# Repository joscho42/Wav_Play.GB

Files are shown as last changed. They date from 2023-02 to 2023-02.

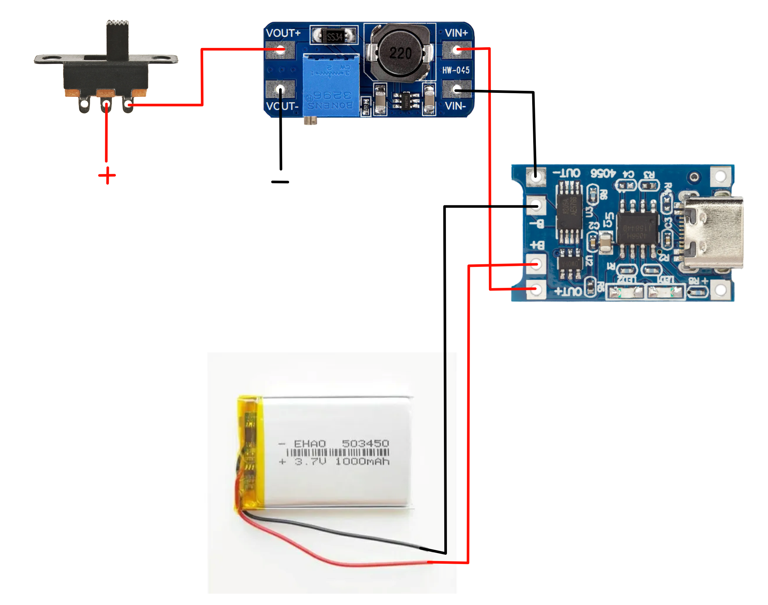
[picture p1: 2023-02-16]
Documentation/Power_managment.png

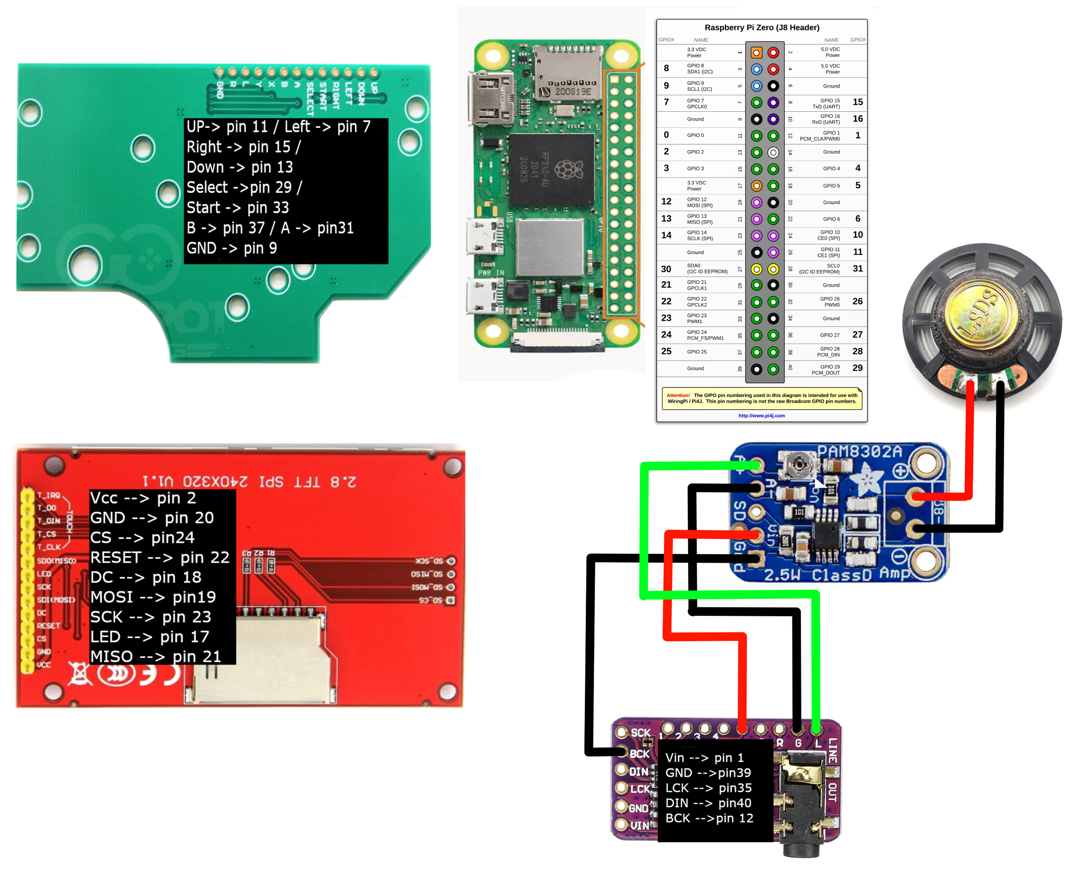
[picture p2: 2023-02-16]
Documentation/Audio_Input_Video.png

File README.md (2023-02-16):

# Wav_Play.GB

Check out the Manual in the Documentation
folder of the rep (German and English)



## About the project

This is a rep for the Wav_Play.GB.

The Wav_Play.GB is a handheld Stepsequencer with up to 192 Steps and up too 6 voices.
It allows you to creat your own sample library and creat tracks on the go all in a familiar form factor.
At it´s heart is a Raspberry pi Zero 2W

It was born out of a University project.
Find out more on Instagram @wav_play.gb

##Turning the device on and off

To turn the Wav_Play.GB on, simply swich the power switch to the right.
To turn it off ** dont´t just switch the power switch to the left **
Go into the menue ofthe pyquencer, navigate to Shut Down and press A.
Wait until the led on the raspberry is of (the screen will still be on and white).
Than Switch the power switch to the left.

## Setting up the SD card and USB

Fist you will want to set up the SD card. For that you simply need to flash our custom img file using 
the Raspberry Pi Imager.
Found here: https://drive.google.com/drive/folders/1ieQOY9xSynMFqbqVy8Zn_2mXZG3F-kP7?usp=share_link

To set up the USB first format it to Fat32 and rename it to PYQUENCER (all caps).
Than Download the Usb_Root folder here:
https://drive.google.com/drive/folders/1ieQOY9xSynMFqbqVy8Zn_2mXZG3F-kP7?usp=share_link
and add the files to the root of your usb.

Congrats. You are all set. Plug the SD card and USB in your Wav_Play.GB and go wild

## Buildguide

A video build guide can be found here: https://youtu.be/5e7-cO_Iyow

#### Installing the Battery

Battery installation is highly dependent of the size of your battery. 
We recoment using a battery with the dimensions: 54x34x10mm
Those dismensions work perfectly with JRodrigos battery holder design 
over on Thingivers (https://www.thingiverse.com/thing:1418834)Power_managment

Simply guide the two leads of your battery through the little hole on the left of the holder 
and torugh the hole in the gameboy case. 
Put the holder and the battery in the compartment using the springs to hold it in place.
Close the compartment and you are done.

#### Wirering of the power side

Power_managment

#### Wiring of the Audio, Video, and input side: 

Audio_Input_Video

***Don´t forget to bridge the two pads under the SCK printing on the Headphone Jack board***

#### Combinig both halves:

When everything is wired up, simply connect the micro usb to usb adapter to the Raspberry and solder in the positif and negative leads to the back of the Raspberry marked 5V and the unmarked pin underneath close to the Power in micro usb port.

## Troubleshooting

If your wav_play.gb doesn´t find your USB you can do a USB Recovery by plugin the USB into your computer and renaming it USB_REC than pluging it backl in your Wav_Play.GB

The device will fix the problem and shut down on it´s own.

Put the USB back into your PC and name it back to PYQUENCER and everything should be fine again.

Video explenation: https://youtu.be/XgMAqk8Z5bY

## Adding your own library

This Video explains how to add your own library
https://www.youtube.com/watch?v=3tRRe0SVF7o

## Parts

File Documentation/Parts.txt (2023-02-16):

-Gameboy Housing
-Rasperry pi Zero W2
-micro sd Karte
-PCM5102 I2S Digital Audio DAC
-Small usb stick minimum 8GB
-3.7v 1800mAh Lipo
-TP4056 Lithium battery charging module
-MT3608 Voltage Booster
-2.8" SPI TFT LCD 
-Micro usb to usb adapter
-PAM8302 Adafruit Mono 2.5W Class D Audio Amplifier
-Gameboy Speaker 
-Gameboy Button PCB 
-ON/OFF switch 
-Cabels
-3D printed parts

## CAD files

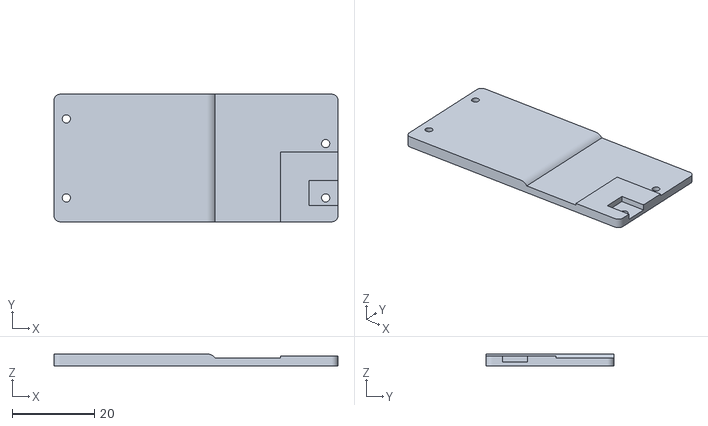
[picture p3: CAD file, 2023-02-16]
3D files/Backplate.stl
69.0 x 31.0 x 3.00

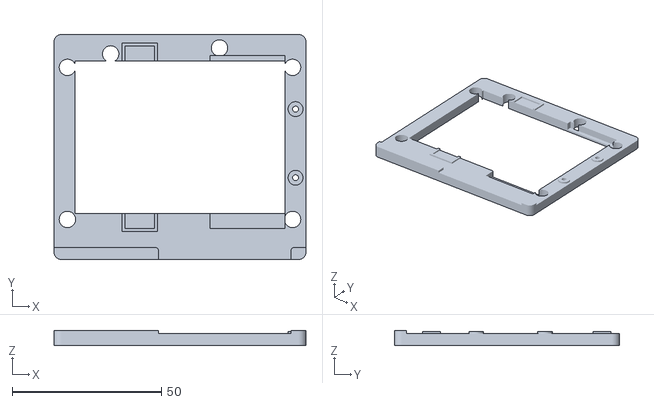
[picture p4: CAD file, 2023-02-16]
3D files/Screen_Holder.stl
84.5 x 75.5 x 5.00

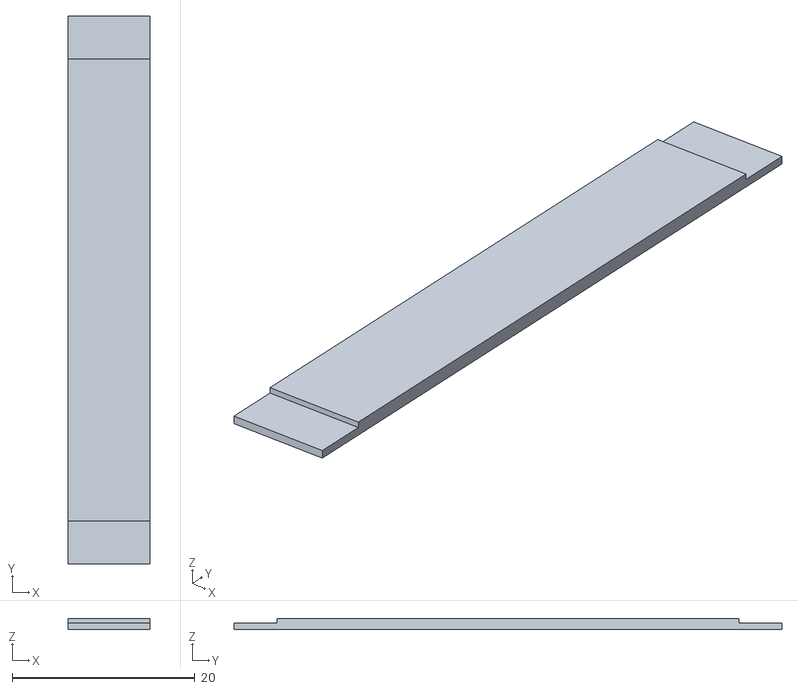
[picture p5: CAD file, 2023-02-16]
3D files/Sceen_Holder_2.stl
9.00 x 60.0 x 1.20

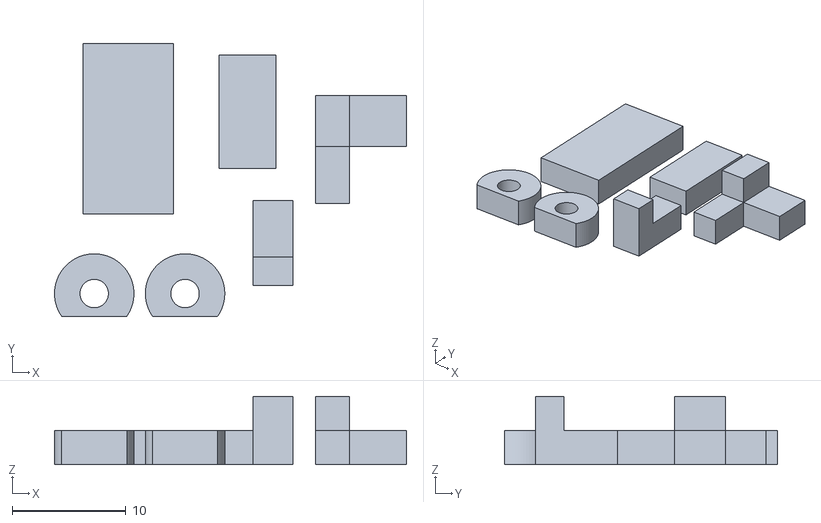
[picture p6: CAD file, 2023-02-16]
3D files/Small_Parts.stl
31.0 x 24.0 x 6.00

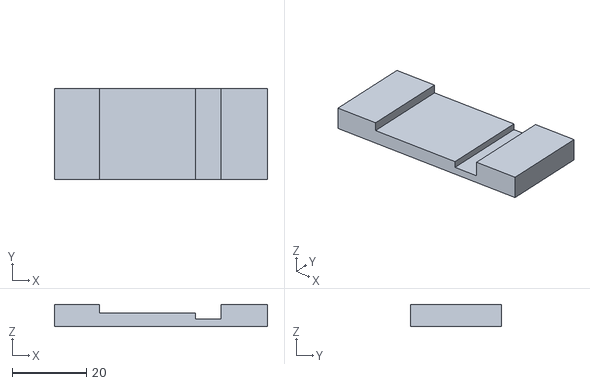
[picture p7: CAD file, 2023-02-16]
3D files/Rpi_Holder.stl
57.5 x 24.5 x 6.00

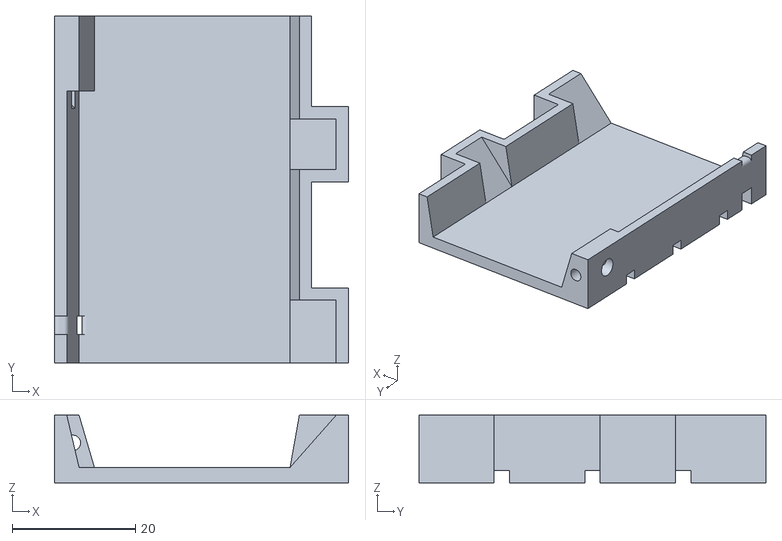
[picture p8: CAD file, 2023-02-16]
3D files/DMG_Battery_Pack(by JRodrigo).STL
47.8 x 56.4 x 11.0

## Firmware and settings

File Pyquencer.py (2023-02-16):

#                                  Setup
# ______________________________________________________________________________


# Importing all the needed libraries
import pydub
from pydub import AudioSegment
import pygame
import time
import os
import sys
import pickle
from gpiozero import Button
from subprocess import call

pygame.mixer.init(frequency=48000, size=-16, channels=16, buffer=256)
pygame.mixer.set_num_channels(32)
pygame.init()


# functions
def Menu(men_running):
    global box_pos
    while men_running == True:
        clock.tick(30)
        keys = pygame.key.get_pressed()
        if keys[pygame.K_e]:
            Exit()
        if keys[pygame.K_UP] and not keys[pygame.K_a] or Up.is_pressed and not A.is_pressed:
            Men_Up_Pressed()
        if keys[pygame.K_DOWN] and not keys[pygame.K_a] or Down.is_pressed and not A.is_pressed:
            Men_Down_Pressed()
        if keys[pygame.K_g] or A.is_pressed:
            if box_pos[1] == 0:
                Seq(True)
                box_pos = [0, 0]
            if box_pos[1] == 2:
                Settings(True)
            if box_pos[1] == 1:
                box_pos = [0, 0]
                if Floppy(True) == True:
                    Seq(True)
            if box_pos[1] == 3:
                call("sudo shutdown -h now", shell=True)
        Vol_up()
        Vol_down()
        window.blit(men_background, [0, 0])
        window.blit(men_box, (men_pos_x[box_pos[0]], men_pos_y[box_pos[1]]))
        pygame.display.flip()
        pygame.event.pump()


def Seq(seq_running):
    global box_pos
    while seq_running:
        clock.tick(30)
        keys = pygame.key.get_pressed()
        if keys[pygame.K_UP] or Up.is_pressed:
            if keys[pygame.K_UP] and keys[pygame.K_a] or Up.is_pressed and A.is_pressed:
                Seq_Choice_Up()
            else:
                Seq_Up_Pressed()
        if keys[pygame.K_DOWN] or Down.is_pressed:
            if keys[pygame.K_DOWN] and keys[pygame.K_a] or Down.is_pressed and A.is_pressed:
                Seq_Choice_Down()
            else:
                Seq_Down_Pressed()
        if keys[pygame.K_a] and keys[pygame.K_b] and keys[
            pygame.K_LEFT] or A.is_pressed and B.is_pressed and Left.is_pressed:
            Carry_Left()
        if keys[pygame.K_a] and keys[pygame.K_b] and keys[
            pygame.K_RIGHT] or A.is_pressed and B.is_pressed and Right.is_pressed:
            Carry_Right()
        if keys[pygame.K_a] and keys[pygame.K_s] or A.is_pressed and Select.is_pressed:
            Empty_Note()
        if keys[pygame.K_LEFT] and not keys[pygame.K_b] or Left.is_pressed and not B.is_pressed:
            if Seq_Left_Pressed() == 0:
                if box_pos[0] > 7:
                    window.blit(seq_box_2, (seq_pos_x[box_pos[0]], seq_pos_y[box_pos[1]]))
                else:
                    window.blit(seq_box, (seq_pos_x[box_pos[0]], seq_pos_y[box_pos[1]]))
                Seq_Text()
                pygame.display.flip()
                time.sleep(0.1)
        if keys[pygame.K_RIGHT] and not keys[pygame.K_b] or Right.is_pressed and not B.is_pressed:
            Seq_Right_Pressed()
        if keys[pygame.K_b] and not keys[pygame.K_a] or B.is_pressed and not A.is_pressed:
            box_pos = [0, 0]
            seq_running = False
        if keys[pygame.K_p] or Start.is_pressed:
            Play_Sequence(True)
        if keys[pygame.K_t] or Select.is_pressed:
            Try_Sound()
        if box_pos[0] > 7:
            window.blit(seq_background_2, [0, 0])
        else:
            window.blit(seq_background_1, [0, 0])
        window.blit(seq_box, (seq_pos_x[box_pos[0]], seq_pos_y[box_pos[1]]))
        Seq_Text()
        pygame.display.flip()
        pygame.event.pump()


def Settings(set_running):
    global box_pos
    while set_running:
        clock.tick(30)
        window.blit(set_background, [0, 0])
        keys = pygame.key.get_pressed()
        if keys[pygame.K_UP] or Up.is_pressed:
            if keys[pygame.K_UP] and keys[pygame.K_a] or Up.is_pressed and A.is_pressed:
                Set_Choice_Up(False)
            else:
                Set_Up_Pressed()
        if keys[pygame.K_DOWN] or Down.is_pressed:
            if keys[pygame.K_DOWN] and keys[pygame.K_a] or Down.is_pressed and A.is_pressed:
                Set_Choice_Down(False)
            else:
                Set_Down_Pressed()
        if keys[pygame.K_LEFT] and keys[pygame.K_a] or Left.is_pressed and A.is_pressed:
            Set_Choice_Down(True)
        if keys[pygame.K_RIGHT] and keys[pygame.K_a] or Right.is_pressed and A.is_pressed:
            Set_Choice_Up(True)
        if keys[pygame.K_b] or B.is_pressed:
            box_pos = [0, 0]
            set_running = False
        window.blit(set_box, (set_pos_x[box_pos[0]], set_pos_y[box_pos[1]]))
        Set_Text()
        pygame.display.flip()
        pygame.event.pump()


def Floppy(floppy_running):
    global box_pos
    open_seq = False
    while floppy_running:
        clock.tick(30)
        keys = pygame.key.get_pressed()
        if keys[pygame.K_s] or A.is_pressed and Start.is_pressed:
            Save_Seq()
            time.sleep(0.2)
        if keys[pygame.K_w]:
            Save_Song(True)
        if keys[pygame.K_l] or A.is_pressed and Select.is_pressed:
            Load_Seq()
            open_seq = True
            box_pos = [0, 0]
            floppy_running = False
        if keys[pygame.K_t] or Select.is_pressed:
            Floppy_Play(0, False, True)
        if keys[pygame.K_UP] or Up.is_pressed:
            Floppy_Up()
        if keys[pygame.K_p] or Start.is_pressed:
            Run_All_Saves(True)
        if keys[pygame.K_DOWN] or Down.is_pressed:
            Floppy_Down()
        if keys[pygame.K_LEFT] or Left.is_pressed:
            Floppy_Left()
        if keys[pygame.K_RIGHT] or Right.is_pressed:
            Floppy_Right()
        if keys[pygame.K_b] or B.is_pressed:
            box_pos = [0, 0]
            floppy_running = False
        window.blit(floppy_background, [0, 0])
        window.blit(floppy_box, (floppy_pos_x[box_pos[0]], floppy_pos_y[box_pos[1]]))
        Floppy_Text()
        pygame.display.flip()
        pygame.event.pump()
    return open_seq


def Exit():
    sys.exit()
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
